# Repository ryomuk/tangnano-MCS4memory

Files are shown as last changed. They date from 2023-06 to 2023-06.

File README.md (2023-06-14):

# tangnano-MCS4memory
Memory system for Intel 4004 using Tang Nano 20K

This document is written mostly in Japanese.
If necessary, please use a translation service such as DeepL (I recommend this) or Google.

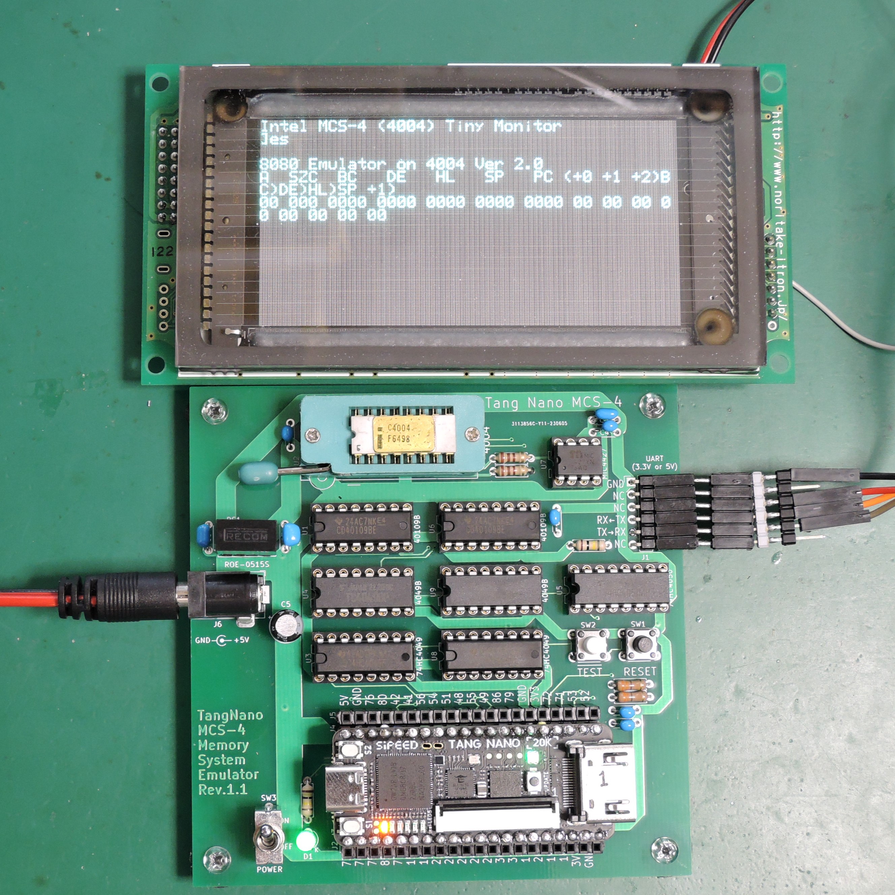
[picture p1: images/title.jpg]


## 概要
[emu8080on4004](https://github.com/ryomuk/emu8080on4004)を動作させるための4004実験ボード(Rev.2.1)の「4004以外の部分」(主にメモリシステム)をTang Nano 20K に実装しました．
これにより，DigikeyやMouserで入手可能な部品とTangNano20KだけでIntel4004を動作させることができます．

## ボードの構成
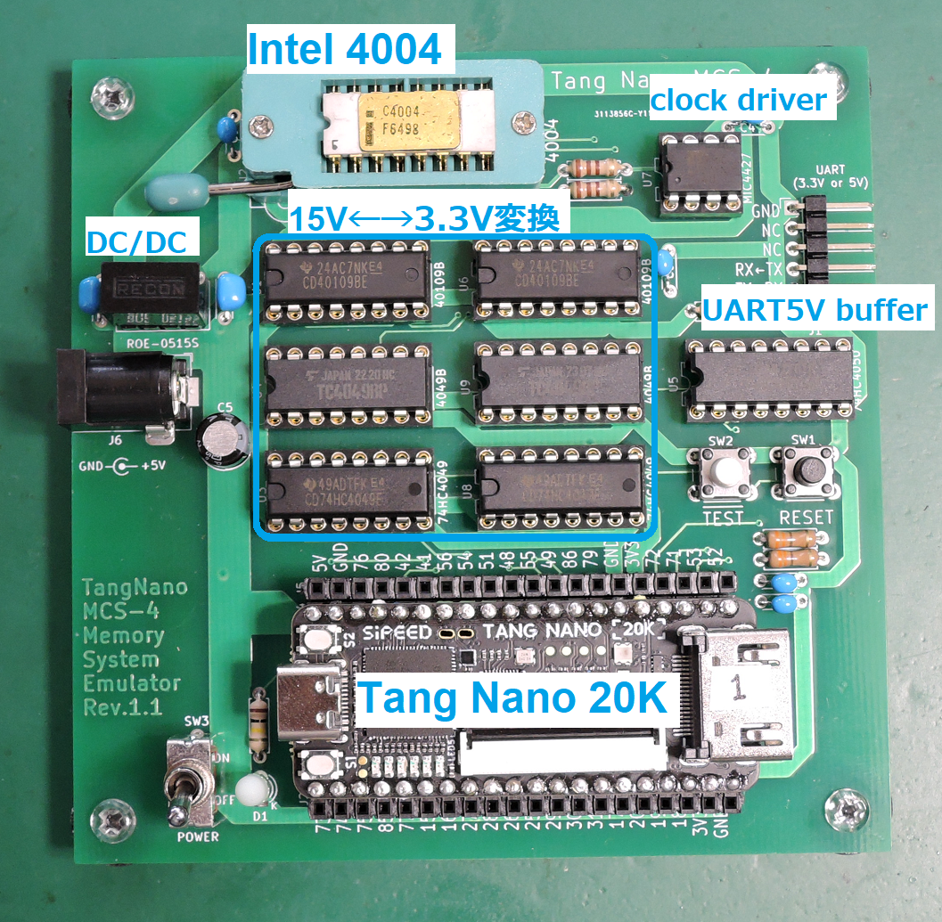
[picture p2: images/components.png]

部品のほとんどはレベル変換用IC(15V←→3.3V, 15Vクロックドライバ, UART用5V耐圧バッファ)です．

## Tang Nano 20Kに実装したもの
- 4002 x 4個 (data ram, 出力ポート)．出力ポートのLEDはRAM0の4個のみ．
- 4289 のプログラムメモリへのアクセス機能(ポート機能は未実装)
- プログラム領域のROM (4KB)
- プログラム領域のRAM (256byte x 256バンク = 64KB)
- 2相クロックジェネレータ

Rev.2.1ボードにおける下記の赤枠の部分がTangNano20Kに実装されています．


## 電源について
一般に，4004の回路は「VSS=-15V, VDD=0V(GND)」もしくは，「VSS=-10V, VDD=+5V, GND=0V」で設計されることが多いですが，3.3VCMOSへのレベル変換を考えた場合，
「VSS=+15V, VDD=0V(GND)」とした方が扱いやすそうだったのでそのようにしています．
(ちなみに，15V系CMOSはVSSとVDDは4004と逆で「VSS=0V(GND)，VDD=+15V」です．)
- +15Vが必要なのは4004とクロック用バッファだけで，消費電流は40mA(電力0.6W)程度なので，5V→15V,1WのDC/DCコンバータの(RECOM, ROE0515S)で生成しています．
- 外部から供給する電源は5Vのみで，消費電流はTangNano(100mA程度)とあわせて250mA程度です．いわゆる普通の5V USB電源でも動作します．

## 4004実験ボード(Rev.2.1)との互換性について
- ソフトウェアはバイナリレベルで互換性があるはずです．
- 4002の出力ポートのLED(計16個)は，RAM0の4個だけTangNanoのオンボードLEDとして実装されています．
- UARTは74HC4050経由にしたので，3.3V, 5Vの両方に対応しているはずです．(動作確認済なのは5Vのみ)

## ブログ
関連する情報が書いてあるかも．
- [Intel 4004 関連記事の目次@ブログの練習](https://blog.goo.ne.jp/tk-80/e/3fa1e2972737c7b7d1b83f4e7bd648a2)

## 更新履歴
- 2023/6/14: 初版公開

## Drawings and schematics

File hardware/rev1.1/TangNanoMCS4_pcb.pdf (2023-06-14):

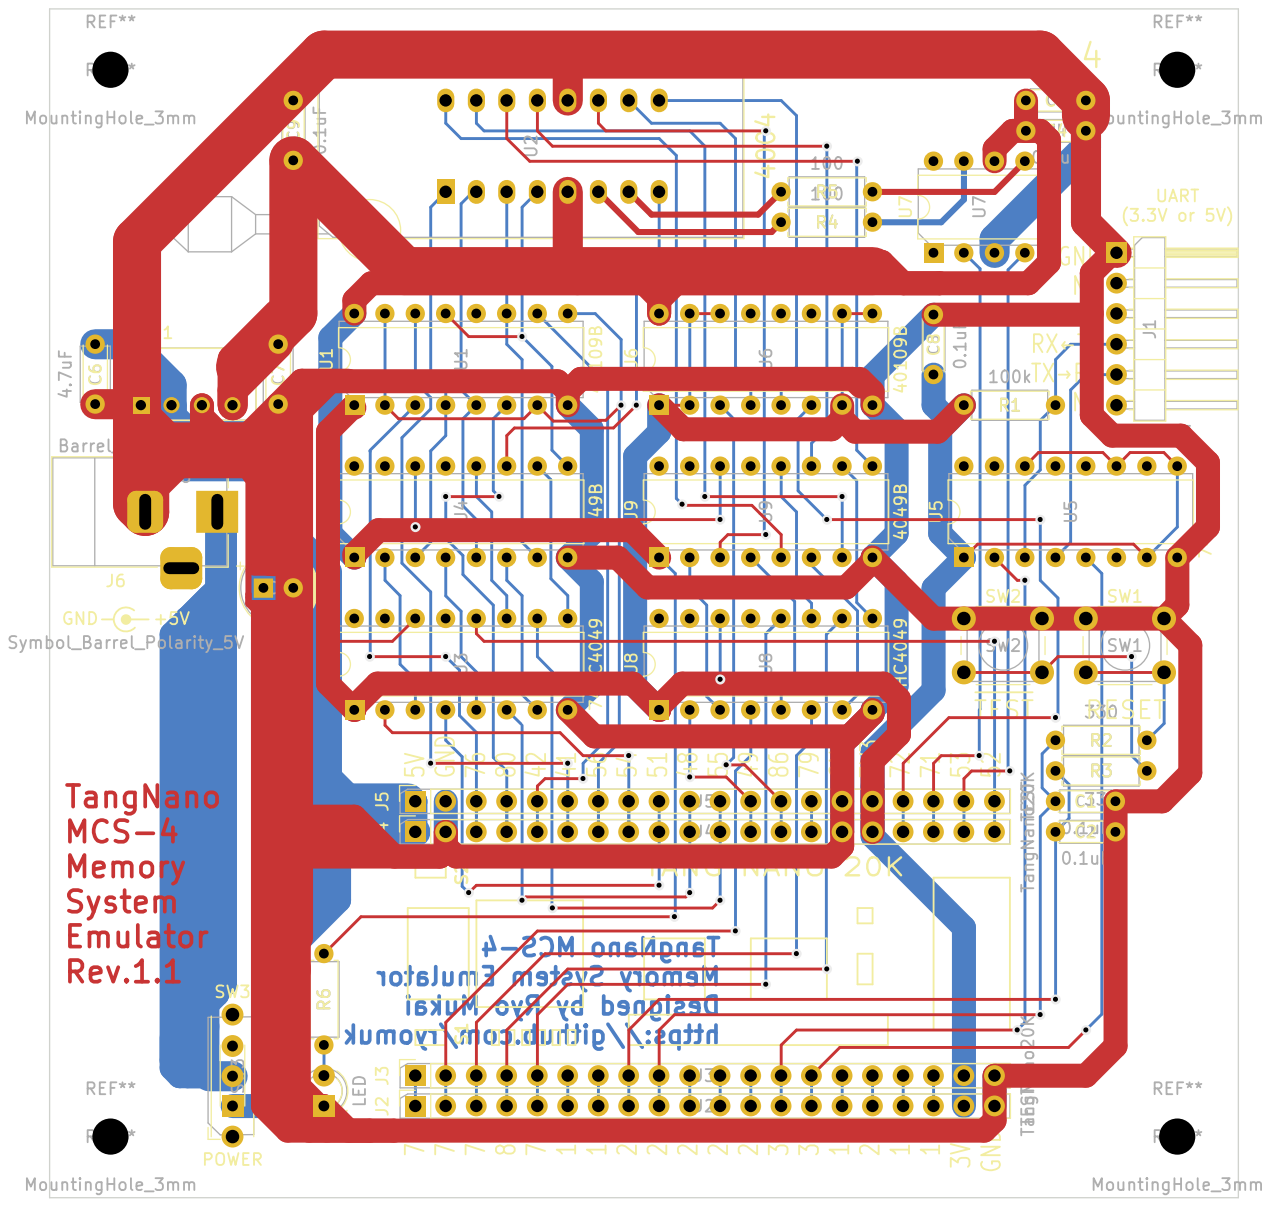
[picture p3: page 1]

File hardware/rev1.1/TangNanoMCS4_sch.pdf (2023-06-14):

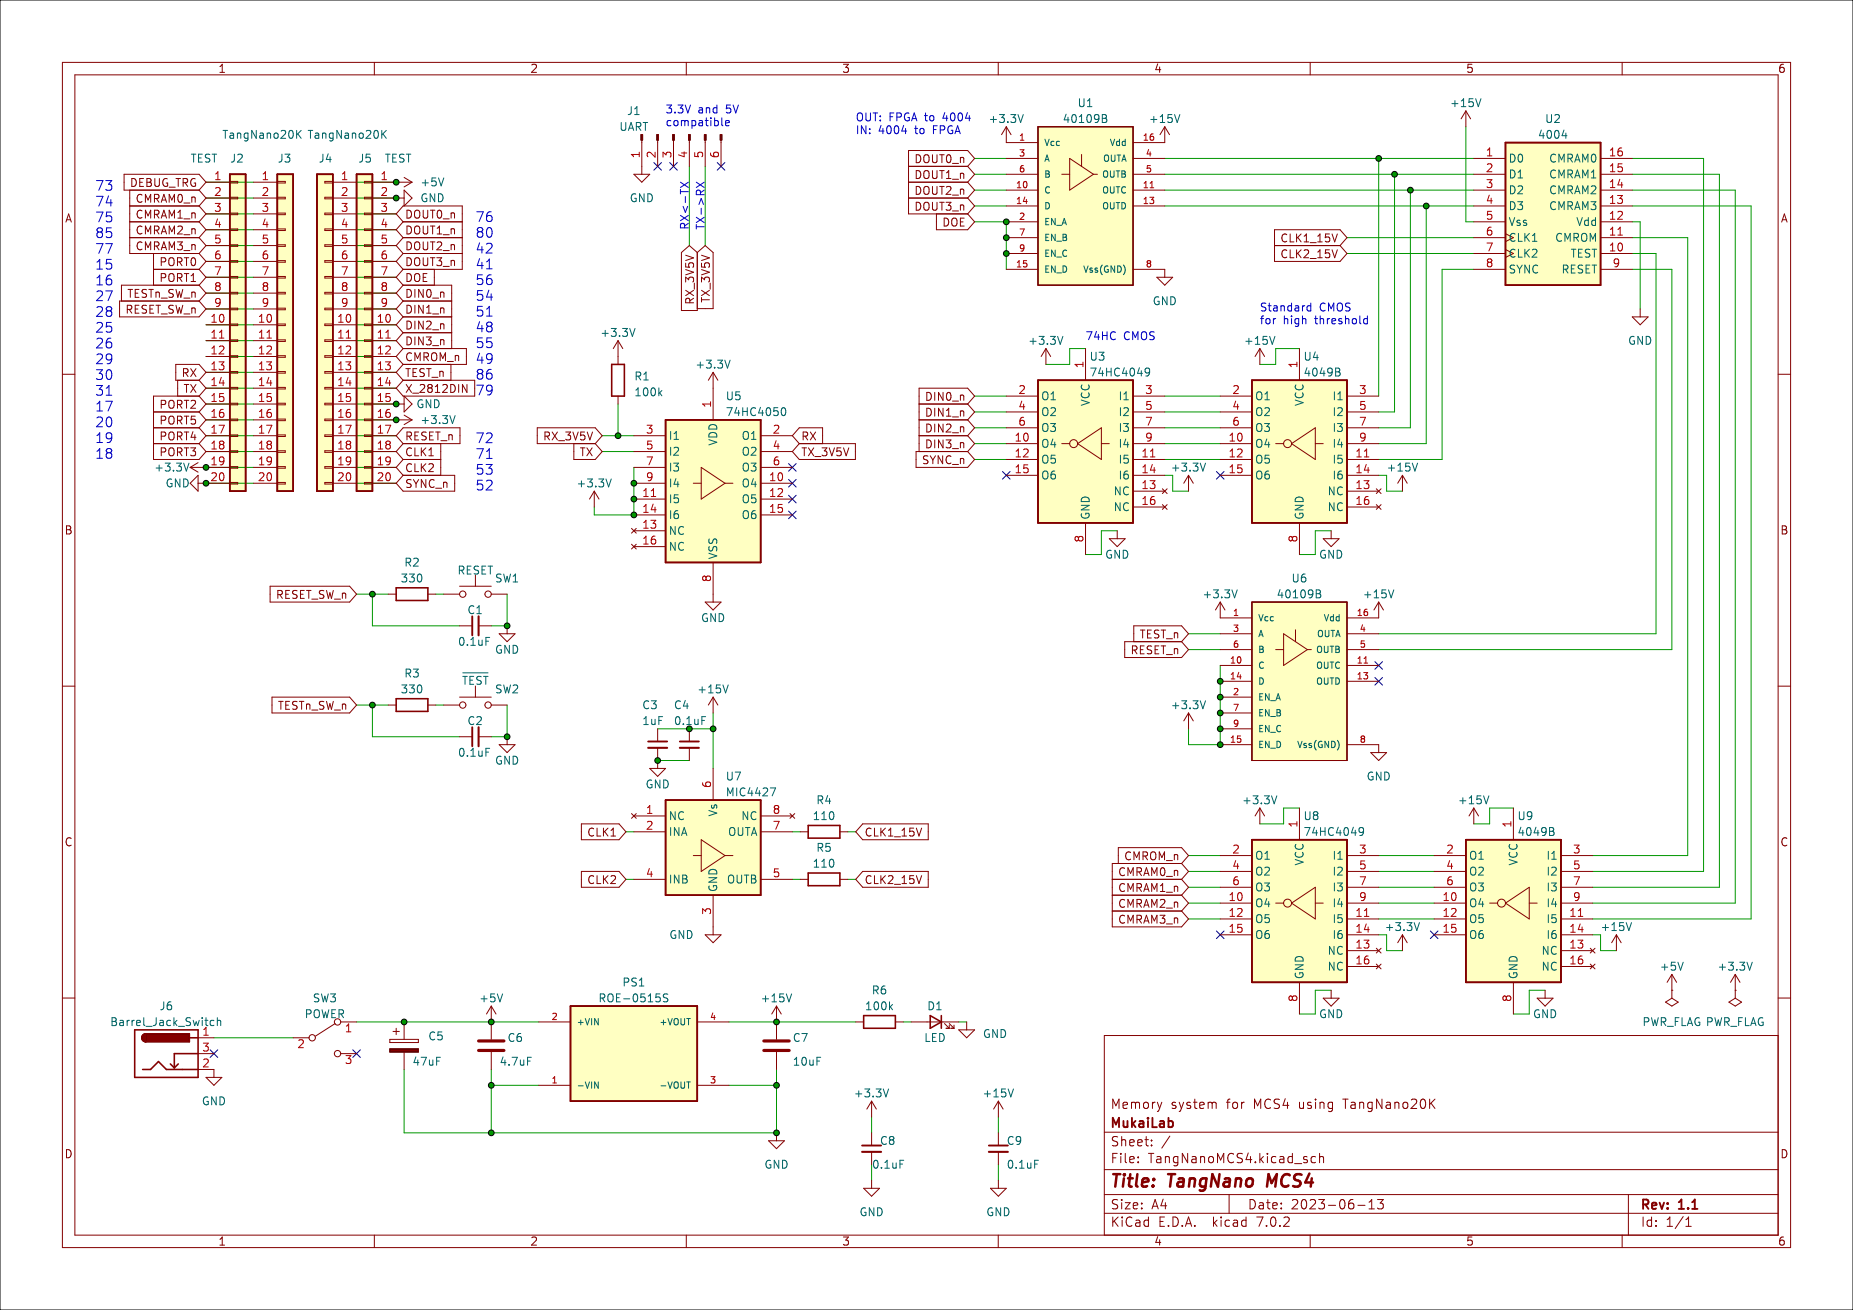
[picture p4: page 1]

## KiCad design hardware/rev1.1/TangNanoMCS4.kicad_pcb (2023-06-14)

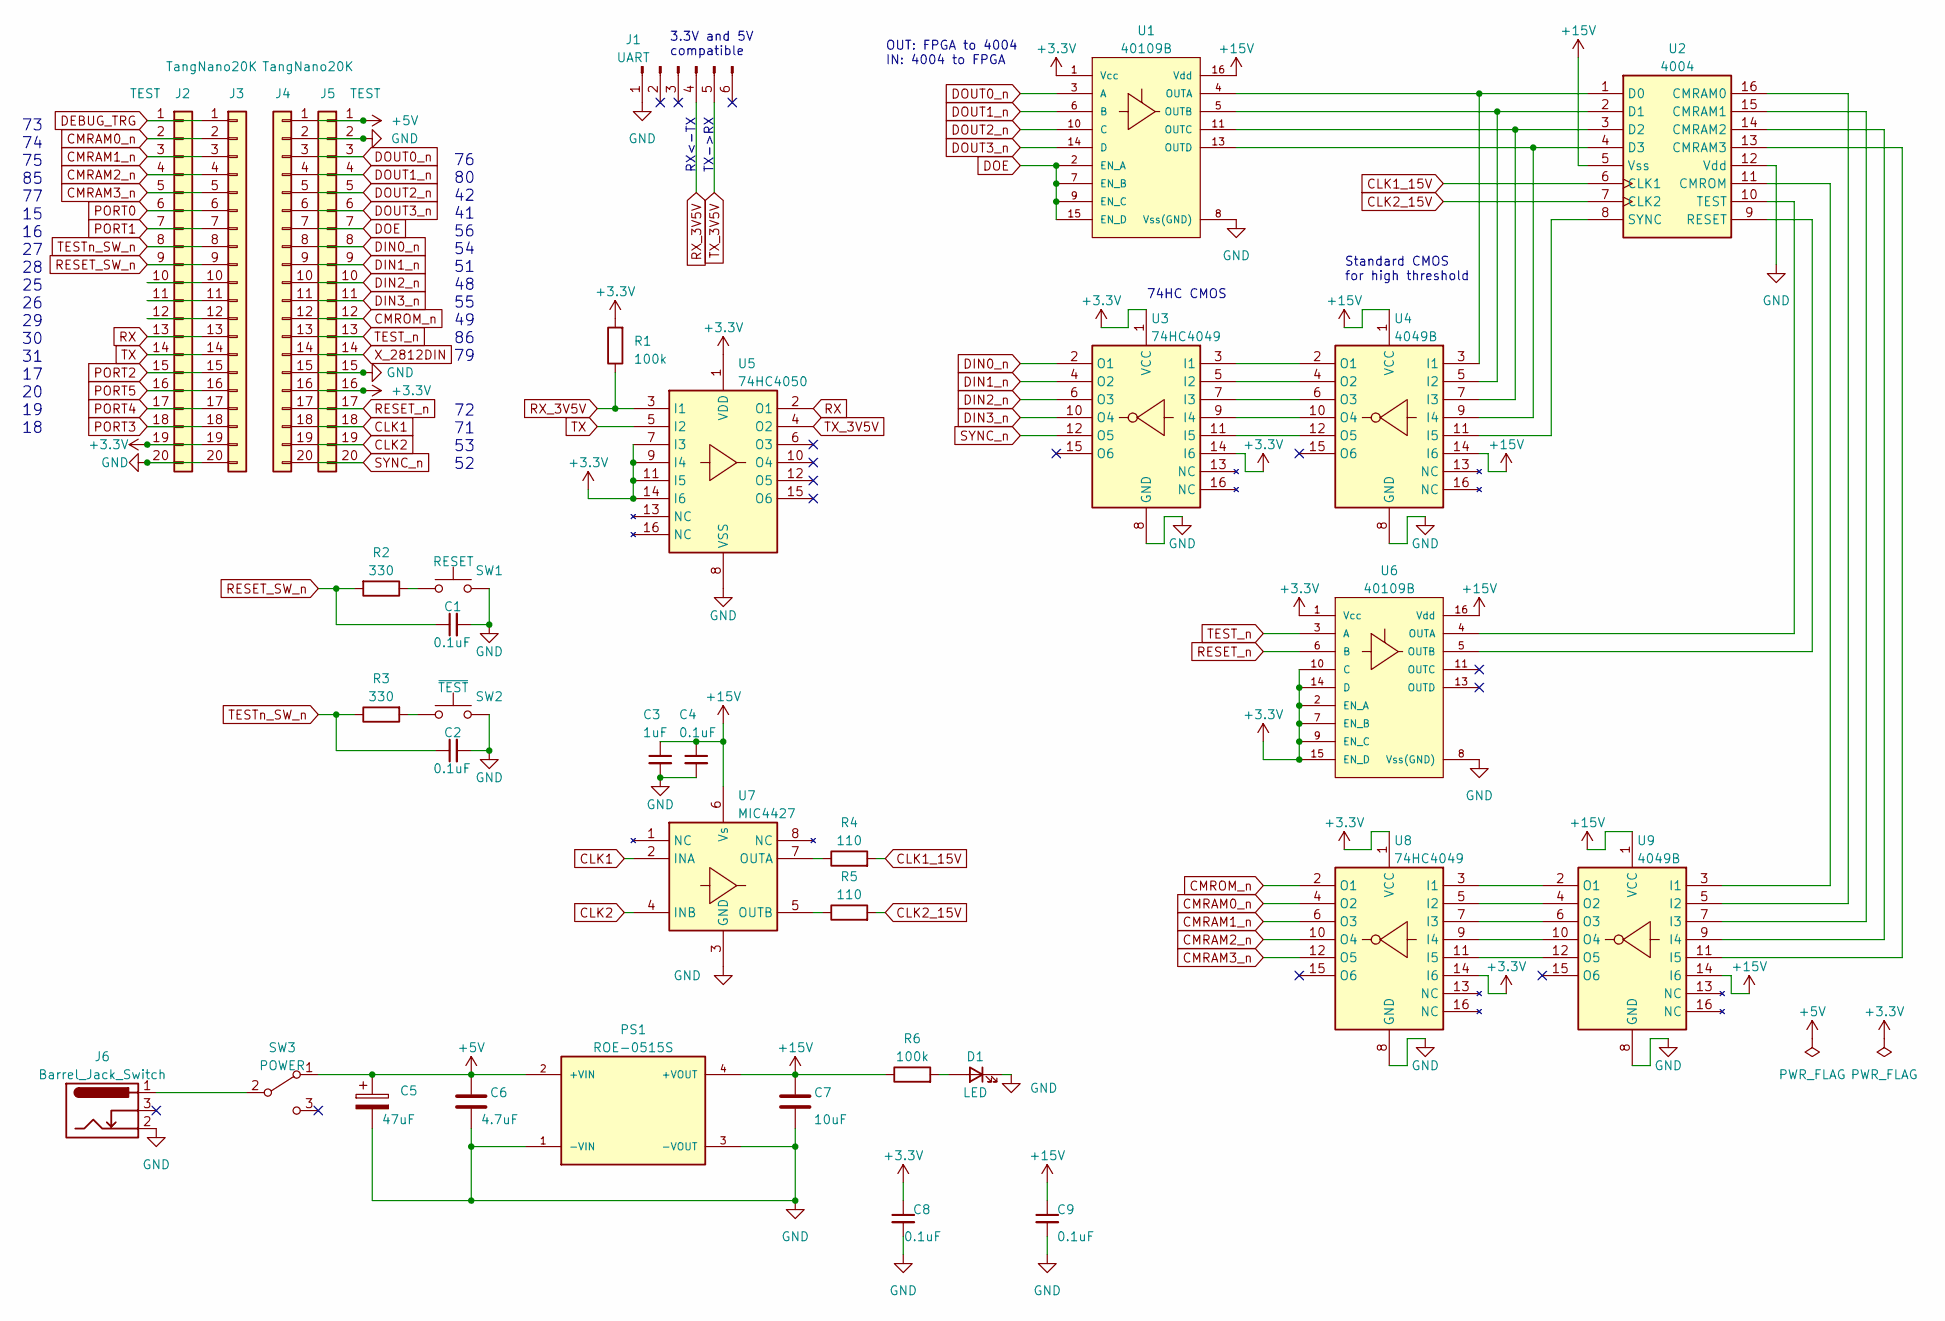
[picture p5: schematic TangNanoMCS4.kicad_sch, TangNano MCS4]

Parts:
C1, C2, C4, C8, C9: 0.1uF; C_Disc_D4.3mm_W1.9mm_P5.00mm
C3: 1uF; C_Disc_D4.3mm_W1.9mm_P5.00mm
C5: 47uF; CP_Radial_D6.3mm_P2.50mm
C6: 4.7uF; C_Disc_D4.7mm_W2.5mm_P5.00mm
C7: 10uF; C_Disc_D4.7mm_W2.5mm_P5.00mm
D1: LED; LED_D3.0mm
J1: UART; PinHeader_1x06_P2.54mm_Horizontal
J2, J5: TEST; PinSocket_1x20_P2.54mm_Vertical
J3, J4: TangNano20K; PinSocket_1x20_P2.54mm_Vertical
J6: Barrel_Jack_Switch; BarrelJack_Horizontal
PS1: ROE-0515S; CONV_ROE-0515S; PARTREV 5
R1, R6: 100k; R_Axial_DIN0207_L6.3mm_D2.5mm_P7.62mm_Horizontal
R2, R3: 330; R_Axial_DIN0207_L6.3mm_D2.5mm_P7.62mm_Horizontal
R4, R5: 110; R_Axial_DIN0207_L6.3mm_D2.5mm_P7.62mm_Horizontal
SW1: RESET; SW_PUSH_6mm_H4.3mm
SW2: ~{TEST}; SW_PUSH_6mm_H4.3mm
SW3: POWER; SW_SPDT_Toggle_with_mount
U1, U6: 40109B; DIP-16_W7.62mm
U2: 4004; DIP_Socket-16_W4.3_W5.08_W7.62_W10.16_W10.9_3M_216-3340-00-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
U3, U8: 74HC4049; DIP-16_W7.62mm
U4, U9: 4049B; DIP-16_W7.62mm
U5: 74HC4050; DIP-16_W7.62mm
U7: MIC4427; DIP-8_W7.62mm

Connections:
+3.3V: C8.1, J2.19, J3.19, J4.16, J5.16, R1.2, U1.1 (Vcc), U3.1 (VCC), U3.14 (I6), U5.1 (VDD), U5.7 (I3), U5.9 (I4), U5.11 (I5), U5.14 (I6), U6.1 (Vcc), U6.2 (EN_A), U6.7 (EN_B), U6.9 (EN_C), U6.10 (C), U6.14 (D), U6.15 (EN_D), U8.1 (VCC), U8.14 (I6)
+5V: C5.1, C6.1, J4.1, J5.1, PS1.2 (+VIN), SW3.1 (A)
+15V: C3.1, C4.1, C7.1, C9.1, PS1.4 (+VOUT), R6.1, U1.16 (Vdd), U2.5 (Vss), U4.1 (VCC), U4.14 (I6), U6.16 (Vdd), U7.6 (Vs), U9.1 (VCC), U9.14 (I6)
CLK1: J4.18, J5.18, U7.2 (INA)
CLK1_15V: R4.2, U2.6 (CLK1)
CLK2: J4.19, J5.19, U7.4 (INB)
CLK2_15V: R5.2, U2.7 (CLK2)
CMRAM0_n: J2.2, J3.2, U8.4 (O2)
CMRAM1_n: J2.3, J3.3, U8.6 (O3)
CMRAM2_n: J2.4, J3.4, U8.10 (O4)
CMRAM3_n: J2.5, J3.5, U8.12 (O5)
CMROM_n: J4.12, J5.12, U8.2 (O1)
DEBUG_TRG: J2.1, J3.1
DIN0_n: J4.8, J5.8, U3.2 (O1)
DIN1_n: J4.9, J5.9, U3.4 (O2)
DIN2_n: J4.10, J5.10, U3.6 (O3)
DIN3_n: J4.11, J5.11, U3.10 (O4)
DOE: J4.7, J5.7, U1.2 (EN_A), U1.7 (EN_B), U1.9 (EN_C), U1.15 (EN_D)
DOUT0_n: J4.3, J5.3, U1.3 (A)
DOUT1_n: J4.4, J5.4, U1.6 (B)
DOUT2_n: J4.5, J5.5, U1.10 (C)
DOUT3_n: J4.6, J5.6, U1.14 (D)
GND: C1.2, C2.2, C3.2, C4.2, C5.2, C6.2, C7.2, C8.2, C9.2, D1.1 (K), J1.1, J2.20, J3.20, J4.2, J4.15, J5.2, J5.15, J6.2, PS1.1 (-VIN), PS1.3 (-VOUT), SW1.2, SW2.2, U1.8 (Vss(GND)), U2.12 (Vdd), U3.8 (GND), U4.8 (GND), U5.8 (VSS), U6.8 (Vss(GND)), U7.3 (GND), U8.8 (GND), U9.8 (GND)
unnamed: D1.2 (A), R6.2
unnamed: J2.10, J3.10
unnamed: J2.11, J3.11
unnamed: J2.12, J3.12
unnamed: R2.1, SW1.1
unnamed: R3.2, SW2.1
unnamed: J6.1, SW3.2 (B)
unnamed: U1.4 (OUTA), U2.1 (D0), U4.3 (I1)
unnamed: U1.5 (OUTB), U2.2 (D1), U4.5 (I2)
unnamed: U1.11 (OUTC), U2.3 (D2), U4.7 (I3)
unnamed: U1.13 (OUTD), U2.4 (D3), U4.9 (I4)
unnamed: U2.16 (CMRAM0), U9.5 (I2)
unnamed: U2.15 (CMRAM1), U9.7 (I3)
unnamed: U2.14 (CMRAM2), U9.9 (I4)
unnamed: U2.13 (CMRAM3), U9.11 (I5)
unnamed: U2.11 (CMROM), U9.3 (I1)
unnamed: U2.9 (RESET), U6.5 (OUTB)
unnamed: U2.8 (SYNC), U4.11 (I5)
unnamed: U2.10 (TEST), U6.4 (OUTA)
unnamed: U3.3 (I1), U4.2 (O1)
unnamed: U3.5 (I2), U4.4 (O2)
unnamed: U3.7 (I3), U4.6 (O3)
unnamed: U3.9 (I4), U4.10 (O4)
unnamed: U3.11 (I5), U4.12 (O5)
unnamed: R4.1, U7.7 (OUTA)
unnamed: R5.1, U7.5 (OUTB)
unnamed: U8.3 (I1), U9.2 (O1)
unnamed: U8.5 (I2), U9.4 (O2)
unnamed: U8.7 (I3), U9.6 (O3)
unnamed: U8.9 (I4), U9.10 (O4)
unnamed: U8.11 (I5), U9.12 (O5)
PORT0: J2.6, J3.6
PORT1: J2.7, J3.7
PORT2: J2.15, J3.15
PORT3: J2.18, J3.18
PORT4: J2.17, J3.17
PORT5: J2.16, J3.16
RESET_SW_n: C1.1, J2.9, J3.9, R2.2
RESET_n: J4.17, J5.17, U6.6 (B)
RX: J2.13, J3.13, U5.2 (O1)
RX_3V5V: J1.4, R1.1, U5.3 (I1)
SYNC_n: J4.20, J5.20, U3.12 (O5)
TEST_n: J4.13, J5.13, U6.3 (A)
TESTn_SW_n: C2.1, J2.8, J3.8, R3.1
TX: J2.14, J3.14, U5.5 (I2)
TX_3V5V: J1.5, U5.4 (O2)
X_2812DIN: J4.14, J5.14

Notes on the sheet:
Standard CMOS for high threshold
OUT: FPGA to 4004 IN: 4004 to FPGA
74HC CMOS
3.3V and 5V compatible
TX->RX
76 80 42 41 56 54 51 48 55 49 86 79
RX<-TX
72 71 53 52
73 74 75 85 77 15 16 27 28 25 26 29 30 31 17 20 19 18

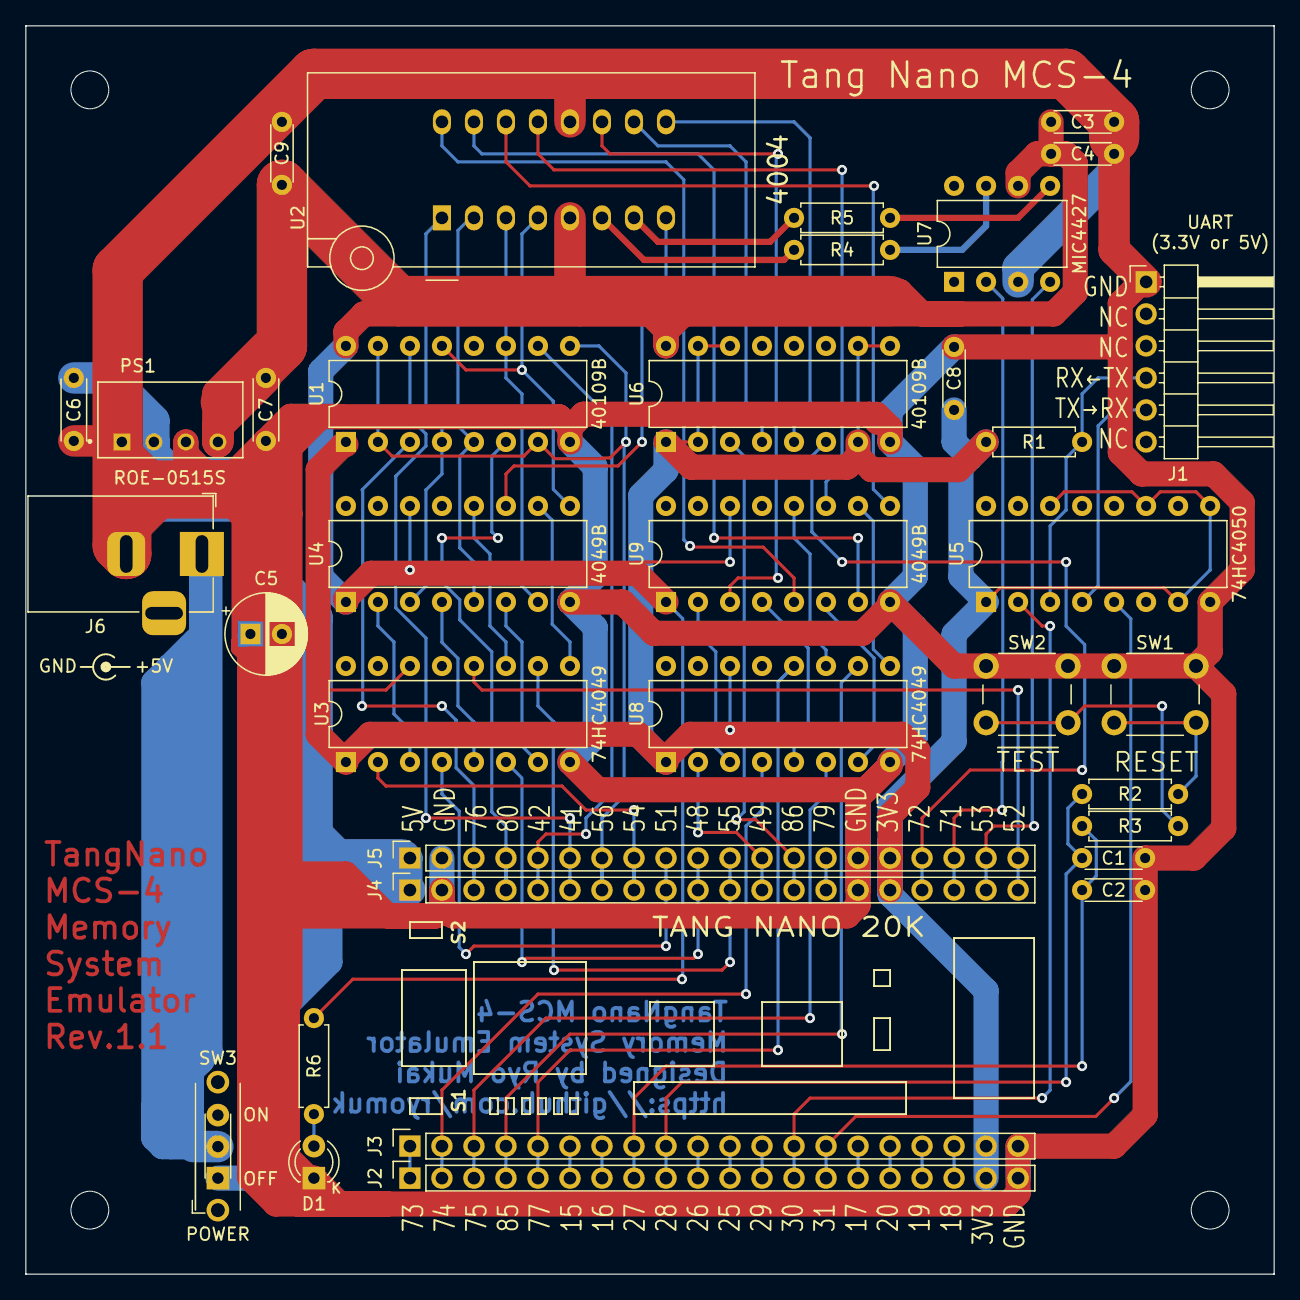
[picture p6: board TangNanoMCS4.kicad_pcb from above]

Board: 2 copper layers, 99.1 x 99.1 mm, 35 parts (0 on the bottom side), 70 nets.

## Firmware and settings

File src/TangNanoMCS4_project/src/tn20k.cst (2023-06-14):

IO_LOC  "led[5]"     20; IO_PORT "led[5]" PULL_MODE=UP DRIVE=8;
IO_LOC  "led[4]"     19; IO_PORT "led[4]" PULL_MODE=UP DRIVE=8;
IO_LOC  "led[3]"     18; IO_PORT "led[3]" PULL_MODE=UP DRIVE=8;
IO_LOC  "led[2]"     17; IO_PORT "led[2]" PULL_MODE=UP DRIVE=8;
IO_LOC  "led[1]"     16; IO_PORT "led[1]" PULL_MODE=UP DRIVE=8;
IO_LOC  "led[0]"     15; IO_PORT "led[0]" PULL_MODE=UP DRIVE=8;
IO_LOC  "ws2812"     79; IO_PORT "ws2812" DRIVE=8; // RGB LED
IO_LOC  "sw1"        88;
IO_LOC  "sw2"        87;
IO_LOC  "sys_clk"     4; IO_PORT "sys_clk" PULL_MODE=UP;

IO_LOC  "debug_trg"  73; IO_PORT "debug_trg" DRIVE=8;
IO_LOC  "cmram_n[0]" 74;
IO_LOC  "cmram_n[1]" 75;
IO_LOC  "cmram_n[2]" 85;
IO_LOC  "cmram_n[3]" 77;
// LED0 15
// LED1 16
IO_LOC  "testn_sw_n" 27; IO_PORT "testn_sw_n" PULL_MODE=UP;
IO_LOC  "reset_sw_n" 28; IO_PORT "reset_sw_n" PULL_MODE=UP;
// 26
// 25
// 29
IO_LOC  "rx"         30;
IO_LOC  "tx"         31; IO_PORT "tx" DRIVE=8;

IO_LOC  "dout_n[0]"  76; IO_PORT "dout_n[0]" DRIVE=8;
IO_LOC  "dout_n[1]"  80; IO_PORT "dout_n[1]" DRIVE=8;
IO_LOC  "dout_n[2]"  42; IO_PORT "dout_n[2]" DRIVE=8;
IO_LOC  "dout_n[3]"  41; IO_PORT "dout_n[3]" DRIVE=8;
IO_LOC  "doe"        56; IO_PORT "doe" DRIVE=8;
IO_LOC  "din_n[0]"   54;
IO_LOC  "din_n[1]"   51;
IO_LOC  "din_n[2]"   48;
IO_LOC  "din_n[3]"   55;
IO_LOC  "cmrom_n"    49;
IO_LOC  "test_n"     86; IO_PORT "test_n"  DRIVE=8;

IO_LOC  "reset_n"    72; IO_PORT "reset_n" DRIVE=8;
IO_LOC  "clk1"       71; IO_PORT "clk1" DRIVE=8;
IO_LOC  "clk2"       53; IO_PORT "clk2" DRIVE=8;
IO_LOC  "sync_n"     52;

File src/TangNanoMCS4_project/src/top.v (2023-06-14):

//---------------------------------------------------------------------------
// Memory system for Intel MCS-4 micro computer set
//
// June 3, 2023
// by Ryo Mukai
//---------------------------------------------------------------------------
module top (
            input	     sys_clk, // clk input
            input	     sw1,
            input	     sw2,
            input	     testn_sw_n, // button for test input
            input	     reset_sw_n, // button for reset input
            output reg [5:0] led, // 6 LEDS pin
            // output	     mclk, // 5.185MHz clock
            
            output reg [3:0] dout_n,
            output	     doe,
            input [3:0]	     din_n,
            input	     cmrom_n,
            input [3:0]	     cmram_n,
            output reg	     clk1, // 740Hz two phase clock 1
            output reg	     clk2, // 740Hz two phase clock 2
            input	     sync_n,
	    output	     tx, // bit 0 of the ram_port0
	    input	     rx,
	    output	     test_n, 
	    output	     reset_n, // reset output to 4004
	    output	     ws2812, // RGB LED
	    output reg	     debug_trg
            );
  
  // parameter	     CLK_FRE  = 27000; //kHz
  // parameter	     PLL_FRE  = 67500; //kHz (5185*13=67405)
  // parameter      MCLK_FRE =  5185; //kHz
  parameter Cycle_A1 = 3'd0;
  parameter Cycle_A2 = 3'd1;
  parameter Cycle_A3 = 3'd2;
  parameter Cycle_M1 = 3'd3;
  parameter Cycle_M2 = 3'd4;
  parameter Cycle_X1 = 3'd5;
  parameter Cycle_X2 = 3'd6;
  parameter Cycle_X3 = 3'd7;

  wire		pll_clk;
  wire		mclk;
  
  reg [23:0]	counter;
  reg [3:0]	cnt_ptom;
  reg [2:0]	cnt_mclk;
  reg [2:0]	cpu_cycle;
  reg		cpu_cycle_reset;
		
  reg [11:0]	rom_address;
  reg		rom_enable;
  wire		rom_oe;		
  wire [7:0]	rom_data;

  reg [7:0]	ram_address;
  reg		ram_command;
  wire		ram_we;
  wire		ram_oe;
  reg		ram_src;		
  wire		ram_cs0, ram_cs1, ram_cs2, ram_cs3;
  wire [3:0]	ram_port0, ram_port1, ram_port2, ram_port3;
  wire [3:0]	ram_dout0, ram_dout1, ram_dout2, ram_dout3;
  wire [3:0]	ram_dout;
  wire		cmram0_n;

  wire [7:0]	pm_data;
  reg		pm_command;		
  wire		pm_we;
      
  reg		nosync;		
  wire [3:0]	opa;
  wire [3:0]	opr;
  wire [3:0]	din;

  Gowin_rPLL pll_clkgen(
                     .clkout(pll_clk), //output clkout = 67.5MHz
	             .clkin(sys_clk)   //input clkin   = 27.0MHz
	             );
  
  //-----------------------------------------------------------------------
  // interface signals
  //-----------------------------------------------------------------------
  assign reset_n = ~(~reset_sw_n | sw1);
  assign test_n = ~testn_sw_n | ~rx | sw2;

  assign tx = ram_port3[0];

  //-----------------------------------------------------------------------
  // Generate 2 phase clock
  //-----------------------------------------------------------------------
  assign mclk = cnt_ptom[3];

  always @(posedge pll_clk) begin
     if (cnt_ptom == 4'd12) // = 13-1 (67.5MHz/5.185MHz = 13.018)
       cnt_ptom <= 4'd0;
     else
       cnt_ptom <= cnt_ptom + 1'd1;
  end
  
  always @(posedge mclk) begin
     if (cnt_mclk == 3'd6)
       cnt_mclk <= 3'd0;
     else
       cnt_mclk <= cnt_mclk + 1'd1;
  end
  always @(negedge mclk) begin
     clk1 <= cnt_mclk[1] | cnt_mclk[2];
     clk2 <= ~(~cnt_mclk[1] & cnt_mclk[2]);
  end

  
  //-----------------------------------------------------------------------
  // ROM, RAM and Program Memory
  //-----------------------------------------------------------------------
  assign cmram0_n = cmram_n[0]; // all RAMs are located in the bank 0
  assign din = ~din_n;

  programmemory pm(.bank({ram_port1, ram_port0}),
		   .romaddr(rom_address[7:0]), .ramaddr(ram_address),
		   .dout(pm_data), .din(din), .opa(opa), .we(pm_we),
		   .clk(clk2), .reset_n(reset_n));
  assign pm_we = pm_command & (cpu_cycle == Cycle_X2);
  
  rom_image rom(.addr(rom_address), .dout(rom_data));
  assign rom_oe = rom_enable
		  & ((cpu_cycle == Cycle_M1) | (cpu_cycle == Cycle_M2))
		  & ~clk2;
  
  assign ram_oe = ram_command
		  & opa[3] // read RAM or RAM port
		  // & (opa != 4'b1010) // read ROM port
		  & (cpu_cycle == Cycle_X2)
		  & ~clk2;

  // write is executed when (ram_we==1) & (opa is write command)
  // at the posedge clk2 in the end of X2
  assign ram_we = ram_command & (cpu_cycle == Cycle_X2);

  ram4002 ram0(.addr(ram_address[5:0]), .din(din), .opa(opa), .we(ram_we),
	       .dout(ram_dout0), .port(ram_port0), .cs(ram_cs0),
	       .clk(clk2), .reset_n(reset_n));
  ram4002 ram1(.addr(ram_address[5:0]), .din(din), .opa(opa),  .we(ram_we),
	       .dout(ram_dout1), .port(ram_port1), .cs(ram_cs1),
	       .clk(clk2), .reset_n(reset_n));
  ram4002 ram2(.addr(ram_address[5:0]), .din(din), .opa(opa),  .we(ram_we),
	       .dout(ram_dout2), .port(ram_port2), .cs(ram_cs2),
	       .clk(clk2), .reset_n(reset_n));
  ram4002 ram3(.addr(ram_address[5:0]), .din(din), .opa(opa),  .we(ram_we),
	       .dout(ram_dout3), .port(ram_port3), .cs(ram_cs3),
	       .clk(clk2), .reset_n(reset_n));

  assign ram_cs0 = ram_address[7:6] == 2'b00;
  assign ram_cs1 = ram_address[7:6] == 2'b01;
  assign ram_cs2 = ram_address[7:6] == 2'b10;
  assign ram_cs3 = ram_address[7:6] == 2'b11;
  
  function [3:0] select;
    input [3:0] x0, x1, x2, x3;
    input [1:0]	addr;
     case (addr)
       2'b00: select = x0;
       2'b01: select = x1;
       2'b10: select = x2;
       2'b11: select = x3;
       default: select = 4'bxxxx;
     endcase  
  endfunction
  assign ram_dout = select(ram_dout0, ram_dout1, ram_dout2, ram_dout3,
			   ram_address[7:6]);
  
  //-----------------------------------------------------------------------
  // data output
  //-----------------------------------------------------------------------
  assign doe = rom_oe | ram_oe;

  //: 000-EFF: ROM area
  //  F00-FFF: Program Memory RAM area
  assign opr = (rom_address[11:8] == 4'b1111) ? pm_data[7:4]: rom_data[7:4];
  assign opa = (rom_address[11:8] == 4'b1111) ? pm_data[3:0]: rom_data[3:0];
  
  //-----------------------------------------------------------------------
  // CPU cycle
  //-----------------------------------------------------------------------
  //     X3  A1  A2  A3  M1  M2  X1  X2  X3  A1
  //CLK1\_/~\_/~\_/~\_/~\_/~\_/~\_/~\_/~\_/~\_
  //CLK2~\_/~\_/~\_/~\_/~\_/~\_/~\_/~\_/~\_/~
  //SYNC\___/~~~~~~~~~~~~~~~~~~~~~~~~~~~\___/
  //
  // 2 phase clocks
  //      6    0    1    2    3    4    5    6    0
  // CLK1 ~~~~~\_________/~~~~~~~~~~~~~~~~~~~~~~~~\____
  //
  // CLK2 /~~~~~~~~~~~~~~~~~~~~~~~~\_________/~~~~~~~~~
  // BUS->CPU                       X__TRUE___X
  // CPU->BUS                  X_____TRUE_____X

  always @(negedge clk1)
    if ( cpu_cycle_reset )
      cpu_cycle <= Cycle_A1;
    else if( cpu_cycle != Cycle_X3 )
      cpu_cycle <= cpu_cycle + 1'd1;

  always @(negedge clk2) begin
     case (cpu_cycle)
       Cycle_M1: dout_n <= ~opr;
       Cycle_M2: dout_n <= ~opa;
       Cycle_X1: dout_n <= ~ram_dout;
     endcase
  end
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
